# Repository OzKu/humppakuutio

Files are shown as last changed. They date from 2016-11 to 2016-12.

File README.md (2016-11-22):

# Humppakuutio - the experience
This is git for our awesome project!

## Parts
- BlueGiga WT32-i (A2DP audiomodule)
- Arduino xyz
- Touchscreen with or without mSD shield
- Opamps for differential audio
- D-Class amplifier
	- Lepai LP-2020A+
- 6x9" car elements
- Some battery
	- LiPo?
	- Lead-acid(12V 7.2Ah)?
	- NiMh?
- Case

## Resources/links

## Idea behind intromenuetc
So I started making introscreen that shows when device is powered up, but nothing is playing.
When it gets streaming is started, it changes to playmenu (own function now).
When phone is disconnected, it changes back to introscreen.

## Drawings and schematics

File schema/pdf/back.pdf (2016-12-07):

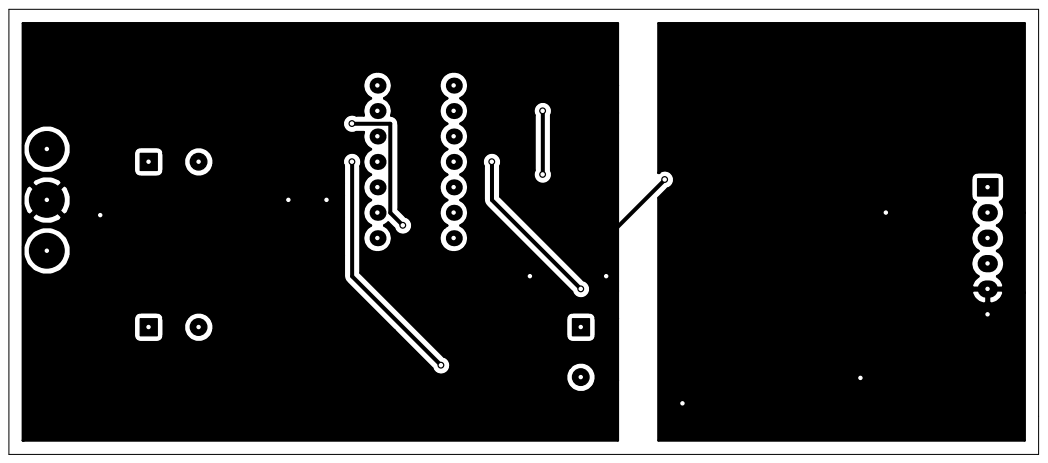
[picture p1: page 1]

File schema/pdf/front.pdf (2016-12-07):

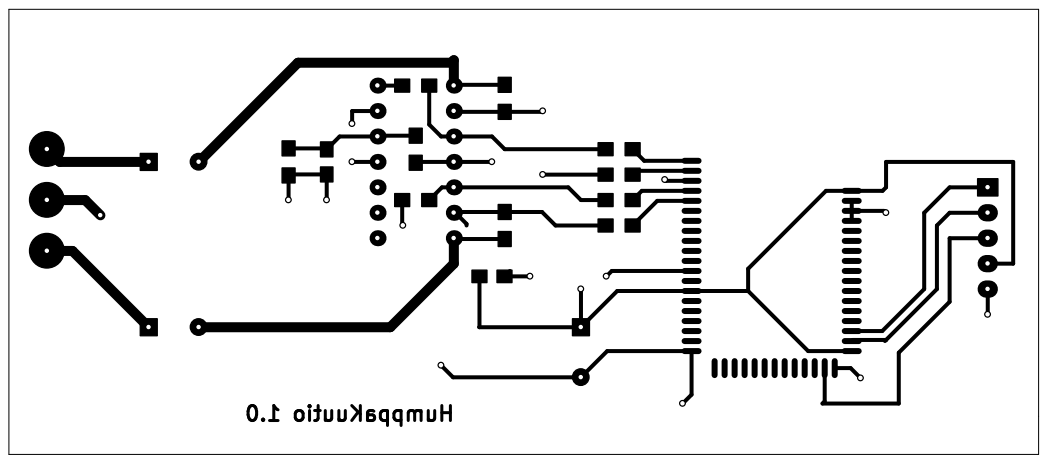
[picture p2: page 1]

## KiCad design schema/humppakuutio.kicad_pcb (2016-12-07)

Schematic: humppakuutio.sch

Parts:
C1, C4, C5: 470u; C_Radial_D12.5_L25_P5
C2, C3: 2u2; C_0805_HandSoldering
P1: CONN_01X05; Pin_Header_Straight_1x05
R1, R2, R3, R4, R5, R6, R7, R8, R9, R10: 10k 0.1%; R_0805_HandSoldering
U1: TL074; DIP-14_W7.62mm
U2: WT32
W1: LEFT; SolderWirePad_single_1-2mmDrill
W2: GNDA; SolderWirePad_single_1-2mmDrill
W3: RIGHT; SolderWirePad_single_1-2mmDrill

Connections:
GNDA: C2.2, C3.1, R6.2, U2.39 (AGND), U2.43 (AGND), U2.48 (AGND), W2.1
GNDD: C1.2, P1.5, U1.11 (V-), U2.2 (DGND), U2.3 (DGND), U2.4 (DGND), U2.18 (DGND), U2.31 (DGND)
unnamed: C2.1, R5.2, R6.1, U1.10 (+)
unnamed: C4.1, W1.1
unnamed: C4.2, R10.1, U1.7
unnamed: C5.1, W3.1
unnamed: C5.2, R9.1, U1.1
unnamed: P1.1, U2.15 (UART_RXD)
unnamed: P1.2, U2.16 (UART_TXD)
unnamed: P1.3, U2.19 (RESET)
unnamed: R1.1, R7.1, U1.5 (+)
unnamed: R1.2, U2.50 (AUDIO_OUT_P_LEFT)
unnamed: R2.2, U2.49 (AUDIO_OUT_N_LEFT)
unnamed: R3.1, R8.1, U1.3 (+)
unnamed: R3.2, U2.47 (AUDIO_OUT_P_RIGHT)
unnamed: R4.1, R9.2, U1.2 (-)
unnamed: R4.2, U2.46 (AUDIO_OUT_N_RIGHT)
unnamed: R2.1, R10.2, U1.6 (-)
VCC: C1.1, C3.2, P1.4, R5.1, U1.4 (V+), U2.1 (VREG_ENA), U2.17 (VDD_IO), U2.37 (VDD_BAT)
VCOM: R7.2, R8.2, U1.8, U1.9 (-)

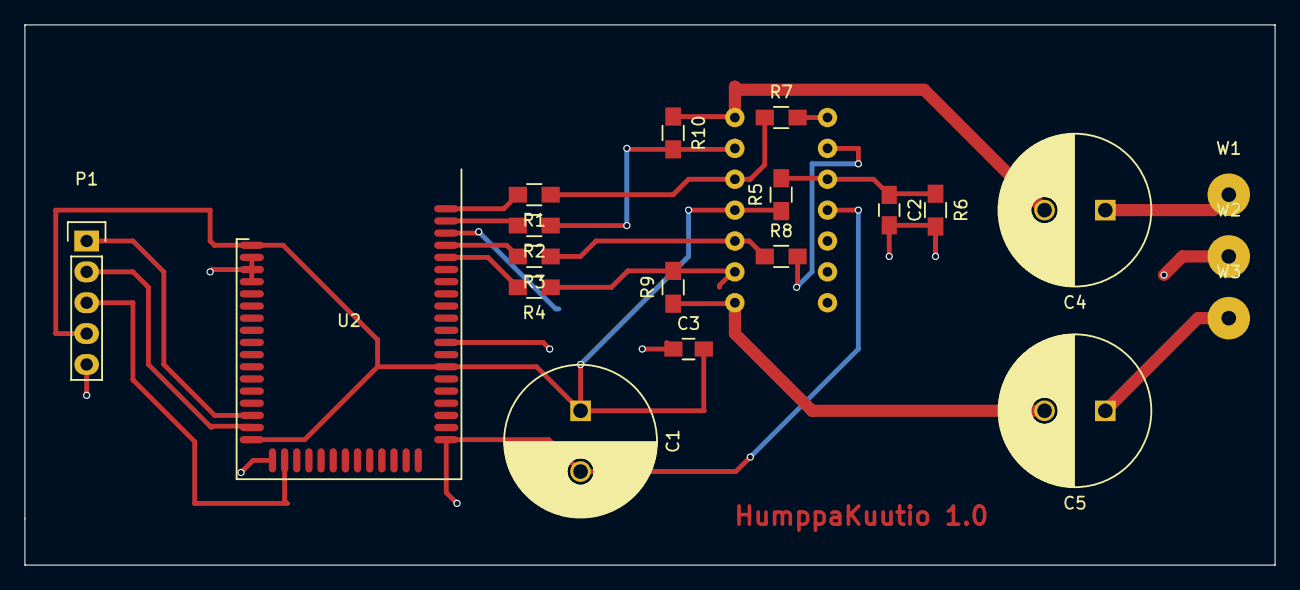
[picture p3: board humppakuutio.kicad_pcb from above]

Board: 2 copper layers, 102.9 x 44.4 mm, 21 parts (1 on the bottom side), 20 nets.

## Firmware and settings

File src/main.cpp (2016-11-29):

#define PLATFORM_ARDUINO_UNO
#define HOST_BAUD                   38400   // works with 8MHz CPU clock
#define IWRAP_BAUD                  38400   // works with 8MHz CPU clock (REQUIRES iWRAP RECONFIGURATION, DEFAULT IS 115200)
#define MODULE_RESET_PIN            12      // optional connection for MCU-based module reset

#define IWRAP_DEBUG
#define IWRAP_INCLUDE_RSP_CALL
#define IWRAP_INCLUDE_RSP_LIST_COUNT
#define IWRAP_INCLUDE_RSP_LIST_RESULT
#define IWRAP_INCLUDE_RSP_SET
#define IWRAP_INCLUDE_EVT_CONNECT
#define IWRAP_INCLUDE_EVT_NO_CARRIER
#define IWRAP_INCLUDE_EVT_PAIR
#define IWRAP_INCLUDE_EVT_READY
#define IWRAP_INCLUDE_EVT_RING
#define IWRAP_INCLUDE_EVT_A2DP_STREAMING_START      // READY
#define IWRAP_INCLUDE_EVT_A2DP_STREAMING_STOP       // READY
#define IWRAP_CONFIGURED

#define LCD

#include <Arduino.h>
#include <GraphicsLib.h>
#include <MI0283QT9.h>
#include <SPI.h>
#include <SimpleTimer.h>

#include "Colors.h"
#include "ConnectionManager.h"
#include "Display.h"
#include "iWRAP.h"
#include "ScrollingText.h"
#include "State.h"

SimpleTimer timer;
Display display;
ConnectionManager connectionManager;
ScrollingText *titleText;
ScrollingText *artistText;

// general helper functions
void process_demo_choice(char b);

// platform-specific helper functions
int serial_out(const char *str);
int serial_out(const __FlashStringHelper *str);
int iwrap_out(int len, unsigned char *data);

void requestSongInfo() {
  iwrap_send_command("AVRCP PDU 31 2", IWRAP_MODE_MUX);  // request track change
  iwrap_send_command("AVRCP PDU 20 1 1", IWRAP_MODE_MUX);  // request title
  iwrap_send_command("AVRCP PDU 20 1 2", IWRAP_MODE_MUX);  // request artist
  iwrap_send_command("AVRCP PDU 31 1 1", IWRAP_MODE_MUX);  // request play pause
}

void onStreamingStart(uint8_t link_id) {
  Serial.println("[EVENT] STREAMING START");
  // paused=false;
  // drawPlayPause(false);
  // requestSongInfo();
  timer.setTimeout(100, requestSongInfo);
  #ifdef LCD
  if (display.getScreen() != PLAY) {
    display.drawPlayMenu();
  }
  #endif
}

void onStreamingStop(uint8_t link_id) {
  Serial.println("[EVENT] STREAMING STOP");
  // paused=true;
  // drawPlayPause(false);
}

void onDisconnect(uint8_t link_id,uint16_t error_code, const char *message) {
  Serial.println("[EVENT] DISCONNECT");
  if(millis()-State::getInstance()->lastIntro > 500) display.drawIntro();
}

void onTrackChange() {
  Serial.println("[EVENT] TRACK CHANGE");
  requestSongInfo();
}

void onPause() {
  Serial.println("[EVENT] PAUSE");
  State::getInstance()->paused = true;
  display.drawPlayPause(false);
  iwrap_send_command("AVRCP PDU 31 1 1", IWRAP_MODE_MUX); // request play pause
}

void onPlay() {
  Serial.println("[EVENT] PLAY");
  State::getInstance()->paused = false;
  display.drawPlayPause(false);
  iwrap_send_command("AVRCP PDU 31 1 1", IWRAP_MODE_MUX); // request play pause
}

void onTitleReceived(const char *rawTitle) {
  String title = String(rawTitle);
  title = title.substring(48, title.length() - 3);

  // TODO: Move to a function
  const char aa[] = { 0x1A, 0x0 };
  const char bb[] = { 0x1B, 0x0 };
  const char cc[] = { 0x1C, 0x0 };
  const char AA[] = { 0x1D, 0x0 };
  const char BB[] = { 0x1E, 0x0 };
  const char CC[] = { 0x1F, 0x0 };

  title.replace("ä", aa);
  title.replace("å", bb);
  title.replace("ö", cc);
  title.replace("Ä", AA);
  title.replace("Å", BB);
  title.replace("Ö", CC);
  title.replace("’", "'");

  titleText->setText(title);
  Serial.println("TITLE RECEIVED: '" + title + "'");
}

void onArtistReceived(const char *rawArtist) {
  String artist = String(rawArtist);
  artist = artist.substring(49, artist.length() - 3);

  // TODO: Move to a function
  const char aa[] = { 0x1A, 0x0 };
  const char bb[] = { 0x1B, 0x0 };
  const char cc[] = { 0x1C, 0x0 };
  const char AA[] = { 0x1D, 0x0 };
  const char BB[] = { 0x1E, 0x0 };
  const char CC[] = { 0x1F, 0x0 };

  artist.replace("ä", aa);
  artist.replace("å", bb);
  artist.replace("ö", cc);
  artist.replace("Ä", AA);
  artist.replace("Å", BB);
  artist.replace("Ö", CC);
  artist.replace("’", "'");

  artistText->setText(artist);
  Serial.println("ARTIST RECEIVED: '" + artist + "'");
}

void onPreviousClick() {
  Serial.println("Previous");
  display.drawPreviousButton(true);
  connectionManager.backward();
}

void onPlayPauseClick() {
  if (State::getInstance()->paused) {
    Serial.println("Play");
    connectionManager.play();
  } else {
    Serial.println("Pause");
    connectionManager.pause();
  }
  display.drawPlayPause(false);
  State::getInstance()->paused = !State::getInstance()->paused;
}

void onNextClick() {
  Serial.println("Next");
  connectionManager.forward();
  display.drawNextButton(true);
}

void onMenuOptionClick(unsigned int optionIndex) {
  switch (optionIndex) {
    case 0:
      connectionManager.setPageMode(3);
      State::getInstance()->pageMode = 0; // TODO: Why does this not match the actual page mode?
      break;
    case 1:
      connectionManager.setPageMode(2);
      State::getInstance()->pageMode = 1;
      break;
    case 2:
      connectionManager.setPageMode(0);
      State::getInstance()->pageMode = 2;
      break;
    case 3:
      if (State::getInstance()->iwrap_autocall_target) {
        Serial.println("=> (1) Disabling round-robin autocall algorithm\n\n");
        State::getInstance()->iwrap_autocall_target = 0;
      } else {
        Serial.println("=> (1) Enabling round-robin autocall algorithm\n\n");
        State::getInstance()->iwrap_autocall_target = 1;
      }
      break;
  }
}

void setup() {
  Serial.begin(HOST_BAUD);
  Serial1.begin(IWRAP_BAUD);

  digitalWrite(MODULE_RESET_PIN, LOW);
  pinMode(MODULE_RESET_PIN, OUTPUT);

  // Setup display
  #ifdef LCD
  display.setupLcd();
  display.drawIntro();

  // Bind display callbacks
  display.onPreviousClick = onPreviousClick;
  display.onPlayPauseClick = onPlayPauseClick;
  display.onNextClick = onNextClick;
  display.onMenuOptionClick = onMenuOptionClick;

  // Create title and artist texts
  titleText = new ScrollingText(display.getLcd());
  titleText->setText("");
  titleText->setPosition(20, 20);
  titleText->setColor(COLOR_WHITE);
  titleText->setBackgroundColor(COLOR_BG);

  artistText = new ScrollingText(display.getLcd());
  artistText->setText("");
  artistText->setPosition(20, 50);
  artistText->setColor(COLOR_WHITE);
  artistText->setBackgroundColor(COLOR_BG);
  #endif

  // Assign transport/debug output
  iwrap_output = iwrap_out;
  #ifdef IWRAP_DEBUG
    iwrap_debug = serial_out;
  #endif

  // Bind iWRAP callbacks
  iwrap_evt_a2dp_streaming_start = onStreamingStart;
  iwrap_evt_a2dp_streaming_stop = onStreamingStop;
  iwrap_evt_track_changed = onTrackChange;
  iwrap_evt_paused = onPause;
  iwrap_evt_playing = onPlay;
  iwrap_evt_title_received = onTitleReceived;
  iwrap_evt_artist_received = onArtistReceived;
  iwrap_evt_no_carrier = onDisconnect;

  // Poll artist and title
  timer.setInterval(5000, requestSongInfo);
}

void loop() {
  #ifdef LCD
  display.update();
  if (display.getScreen() == PLAY) {
    titleText->update();
    artistText->update();
  }
  #endif

  timer.run();
  connectionManager.update();

  // check for incoming host data
  uint16_t result;
  if ((result = Serial.read()) < 256)
  {
    process_demo_choice(result & 0xFF);
  }
}

int serial_out(const char *str) {
  return Serial.print(str);
}

int serial_out(const __FlashStringHelper *str) {
  return Serial.print(str);
}

int iwrap_out(int len, unsigned char *data) {
  return Serial1.write(data, len);
}

void process_demo_choice(char b) {
  // check for RESET command ("0")
  if (b == '0') {
    serial_out("=> (0) Performing hardware reset on iWRAP module\n\n");
    digitalWrite(MODULE_RESET_PIN, HIGH);
    delay(5);
    digitalWrite(MODULE_RESET_PIN, LOW);
    iwrap_pending_commands = 0; // normally handled by the parser, but this is a hard reset
  } else if (b == '1') {
    if (State::getInstance()->iwrap_autocall_target) {
      serial_out("=> (1) Disabling round-robin autocall algorithm\n\n");
      State::getInstance()->iwrap_autocall_target = 0;
    } else {
      serial_out("=> (1) Enabling round-robin autocall algorithm\n\n");
      State::getInstance()->iwrap_autocall_target = 1;
    }
  } else if (b == '2') {
    serial_out("=> (2) Setting page mode to 3 (discoverable and connectable)\n\n");
    connectionManager.sendCommand("SET BT PAGEMODE 3");
  } else if (b == '3') {
    serial_out("=> (3) Setting page mode to 2 (undiscoverable, but connectable)\n\n");
    connectionManager.sendCommand("SET BT PAGEMODE 2");
  } else if (b == '4') {
    serial_out("=> (4) Setting page mode to 0 (undiscoverable and unconnectable)\n\n");
    connectionManager.sendCommand("SET BT PAGEMODE 0");
  } else if (b =='5') {
    //drawIntro();
    display.drawSetupMenu(4);
  } else if (b =='6') {
    iwrap_send_command("AVRCP PDU 20 1 1", IWRAP_MODE_MUX);
  } else if (b =='7') {
    iwrap_send_command("AVRCP PDU 20 1 2", IWRAP_MODE_MUX);
  } else if (b =='8') {
    iwrap_send_command("AVRCP PDU 31 1", IWRAP_MODE_MUX);
  } else if (b =='9') {
    iwrap_send_command("AVRCP PDU 31 2", IWRAP_MODE_MUX);
  } else if (b == 'a') {
    iwrap_send_command("AVRCP PDU 31 1 1", IWRAP_MODE_MUX);
  }
}

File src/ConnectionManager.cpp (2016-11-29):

#include "ConnectionManager.h"

#include "State.h"

void ConnectionManager::play() {
  sendCommand("AVRCP PLAY");
}

void ConnectionManager::pause() {
  sendCommand("AVRCP PAUSE");
}

void ConnectionManager::backward() {
  sendCommand("AVRCP BACKWARD");
}

void ConnectionManager::forward() {
  sendCommand("AVRCP FORWARD");
}

void ConnectionManager::setPageMode(unsigned int pageMode) {
  char command[30];
  sprintf(command, "SET BT PAGEMODE %d", pageMode);
  sendCommand(command);
}

void ConnectionManager::enableAutoCall(bool enable) {
  
}

void ConnectionManager::update() {
  // manage iWRAP state machine
  if (!iwrap_pending_commands) {
    // no pending commands, some state transition occurring
    if (state) {
      // not idle, in the middle of some process
      if (state == IWRAP_STATE_UNKNOWN) {
        // reset all detailed state trackers
        initialized = 0;
        pairings = 0;
        pending_calls = 0;
        pending_call_link_id = 0xFF;
        connected_devices = 0;
        active_connections = 0;

        // send command to test module connectivity
        Serial.print(F("Testing iWRAP communication...\n"));
        iwrap_send_command("AT", mode);
        state = IWRAP_STATE_PENDING_AT;

        // initialize time reference for connectivity test timeout
        time_ref = millis();
      } else if (state == IWRAP_STATE_PENDING_AT) {
        // send command to dump all module settings and pairings
        Serial.print(F("Getting iWRAP settings...\n"));
        iwrap_send_command("SET", mode);
        state = IWRAP_STATE_PENDING_SET;
      } else if (state == IWRAP_STATE_PENDING_SET) {
        // send command to show all current connections
        Serial.print(F("Getting active connection list...\n"));
        iwrap_send_command("LIST", mode);
        state = IWRAP_STATE_PENDING_LIST;
      } else if (state == IWRAP_STATE_PENDING_LIST) {
        // all done!
        if (!initialized) {
            initialized = 1;
            Serial.print(F("iWRAP initialization complete\n"));
        }
        printConnectionMap();
        printDemoMenu();
        iwrap_send_command("AVRCP PDU 31 2", IWRAP_MODE_MUX);
        state = IWRAP_STATE_IDLE;
      } else if (state == IWRAP_STATE_PENDING_CALL && !pending_calls) {
        // all done!
        Serial.print(F("Pending call processed\n"));
        state = IWRAP_STATE_IDLE;
      }
    } else if (initialized) {
      // idle
      if (pairings && State::getInstance()->iwrap_autocall_target > connected_devices && !pending_calls
                         && (!autocall_last_time || (millis() - autocall_last_time) >= autocall_delay_ms)) {
        char cmd[] = "CALL AA:BB:CC:DD:EE:FF 19 A2DP";      // A2DP
        //char cmd[] = "CALL AA:BB:CC:DD:EE:FF 17 AVRCP";     // AVRCP
        //char cmd[] = "CALL AA:BB:CC:DD:EE:FF 111F HFP";     // HFP
        //char cmd[] = "CALL AA:BB:CC:DD:EE:FF 111E HFP-AG";  // HFP-AG
        //char cmd[] = "CALL AA:BB:CC:DD:EE:FF 11 HID";       // HID
        //char cmd[] = "CALL AA:BB:CC:DD:EE:FF 1112 HSP";     // HSP
        //char cmd[] = "CALL AA:BB:CC:DD:EE:FF 1108 HSP-AG";  // HSP-AG
        //char cmd[] = "CALL AA:BB:CC:DD:EE:FF * IAP";        // IAP
        // char cmd[] = "CALL AA:BB:CC:DD:EE:FF 1101 RFCOMM";  // SPP
        char *cptr = cmd + 5;

        // find first unconnected device
        for (; connectionMap[autocall_index]->active_links; autocall_index++);

        // write MAC string into call command buffer and send it
        iwrap_bintohexstr((uint8_t *)(connectionMap[autocall_index]->mac.address), 6, &cptr, ':', 0);
        char s[21];
        sprintf(s, "Calling device #%d\r\n", autocall_index);
        Serial.print(s);
        iwrap_send_command(cmd, mode);
        autocall_last_time = millis();
      }
    }
  }

  // check for incoming iWRAP data
  #if defined(PLATFORM_ARDUINO_UNO)
      if ((result = Serial1.read()) < 256) iwrap_parse(result & 0xFF, iwrap_mode);
  #elif defined(PLATFORM_TEENSY2)
      if ((result = Serial1.read()) < 256) iwrap_parse(result & 0xFF, iwrap_mode);
  #endif

  // check for timeout if still testing communication
  if (!initialized && state == IWRAP_STATE_PENDING_AT) {
      if (millis() - time_ref > 5000) {
          Serial.print(F("ERROR: Could not communicate with iWRAP module\n"));
          state = IWRAP_STATE_COMM_FAILED;
          iwrap_pending_commands = 0; // normally handled by the parser, but comms failed
      }
  }
}

uint8_t ConnectionManager::sendCommand(const char *cmd) {
  return iwrap_send_command(cmd, mode);
}

uint8_t ConnectionManager::findPairingFromMac(const iwrap_address_t *mac) {
    uint8_t i;
    for (i = 0; i < pairings; i++) {
        if (memcmp(&(connectionMap[i]->mac), mac, sizeof(iwrap_address_t)) == 0) return i;
    }
    return i >= pairings ? 0xFF : i;
}

uint8_t ConnectionManager::findPairingFromLinkId(uint8_t link_id) {
    // NOTE: This implementation walks through the iwrap_connection_t struct memory
    // starting at the first link ID (A2DP #1) and going all the way to the end (if
    // necessary). This means it is contingent on the structure keeping this memory
    // arrangement, where the last set of whatever is contained there is always the
    // set of link IDs.

    uint8_t i, j, *idptr;
    for (i = 0; i < pairings; i++) {
        idptr = &(connectionMap[i]->link_a2dp1);
        for (j = 6; j < sizeof(iwrap_connection_t); j++, idptr++) if (idptr[0] == link_id) return i;
    }
    return 0xFF;
}
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

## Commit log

2016-10-13 Add button icons
2016-11-22 Fixed filenames, added gitignore, added libraries
    Fixed filenames when using linux CASE does matter.
    Added .gitignore to ignore buildfiles (using atom arduino-upload)
    Added new folder called libraries where every used library is located, so you can just copy those into arduino-libraries
    [iWRAP.h]
2016-11-22 Added working setup menu
    Made fully functional setup menu with those four default buttons, same as in demo. To acces it, in PLAY screen, you'll have to click on right top corner, on INTRO screen, it's in O.
2016-12-05 First attempt to make hw
    [humppakuutio.kicad_pcb, humppakuutio.sch]
2016-12-05 Hardware, attempt 2
    [humppakuutio.kicad_pcb, humppakuutio.sch]
2016-12-07 HW ready for making
    [humppakuutio.kicad_pcb]
2016-12-17 Arduino Mega Shield 0.1
    [humppakuutio.sch]
